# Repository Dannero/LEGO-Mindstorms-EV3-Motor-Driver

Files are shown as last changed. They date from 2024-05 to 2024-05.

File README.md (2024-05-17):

# LEGO Mindstorms EV3 Motor Driver

The following files are a part of my bachelor's thesis, in which I created custom motor driver PCBs with integrated microcontrollers, designed enclosures for these drivers, and created EV3-G blocks that allow the EV3 brick to communicate with the driver and carry out UART communication. 

---

### Driver_Arduino
This directory contains code for the [ev3dev](https://www.ev3dev.org/) OS and an Arduino Uno with an [Adafruit Motor Driver shield](https://learn.adafruit.com/adafruit-motor-shield/overview) and allows the EV3 with the ev3dev OS installed to control motors via I2C.

---

### Driver_V0.1
This directory contains the code for the first version of the custom driver in the `Driver_Code` directory, as well as PCB and 3D case files for manufacturing and printing. This PCB design is faulty and has some missing components, so I strongly advise to use the V0.2 driver.

---

### Driver_V0.2
Directory with source code and design files for the second iteration of the custom Driver, now more compact and able to run motors with higher performance, while being significantly more efficient in an idle state. 

---

### EV3-G_Blocks
Blocks for the *LEGO EV3 Lab Software* and their source code are situated in this directory. The `Thesis_Block.ev3b` allows the EV3 to communicate via the LEGO UART Sensor Protocol, built on the UART protocol, as well as control the motors connected to the motor driver via both I2C and the aforementioned UART-based protocols.

The `Dexter_Mod.ev3b` block is a modified version of the *Dexter Industries I2C Block*, available [here](https://github.com/DexterInd/EV3_Dexter_Industries_Sensors/blob/master/Dexter.ev3b). My modifications to this block fix the long-standing issue of the I2C communication functionality, where the maximum value of a sent byte is `0x7F`.

---

### Driver_Manual.pdf
This document contains all the necessary info to create the second version of the custom driver, get it up and running and use EV3-G block to control it.

---

### Future Work
The next iteration of the motor driver will take on a different approach, with the connection to the EV3 going wireless. Stay tuned!

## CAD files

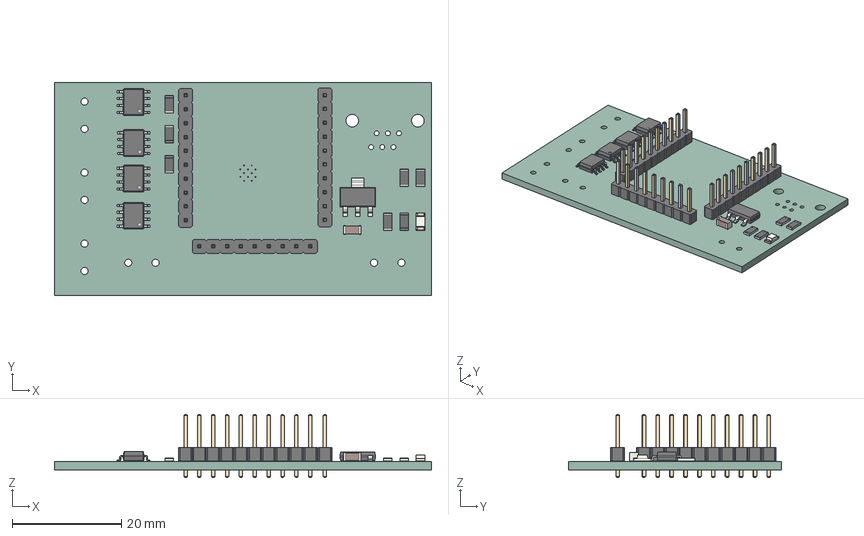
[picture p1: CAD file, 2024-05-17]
Driver_V0.2/V0.2_Case_Design/PCB/driver_v2.step
69.0 x 39.0 x 11.5 mm
SOIC_8_39x49mm_P127mm x 4
C_1206_3216Metric
R_1206_3216Metric x 7
PinHeader_1x09_P254mm_Vertical
PinHeader_1x10_P254mm_Vertical x 2
LED_1206_3216Metric
SOT_223
driver_v2_PCB

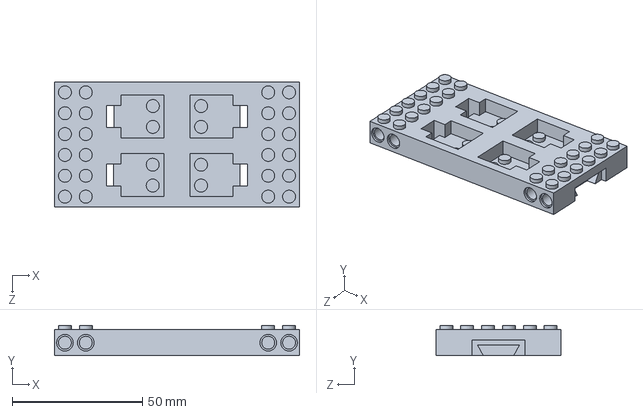
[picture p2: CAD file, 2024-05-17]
Driver_V0.2/V0.2_Case_Design/top.SLDPRT
94.0 x 11.7 x 48.0 mm

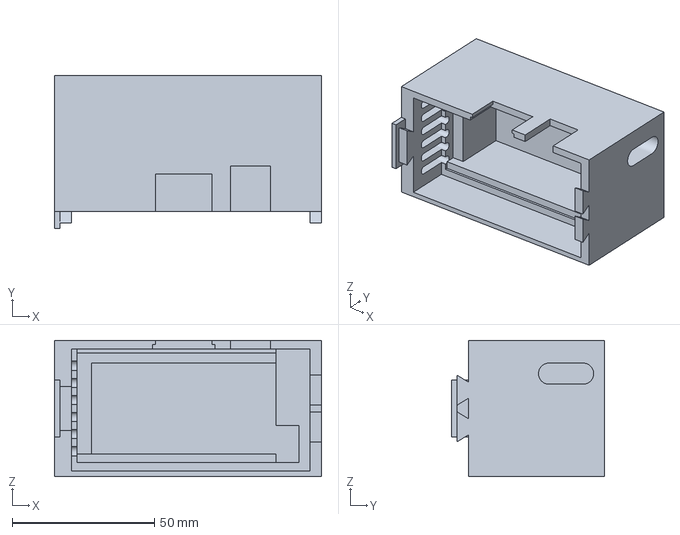
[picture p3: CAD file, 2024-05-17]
Driver_V0.2/V0.2_Print_Files/Bottom.3MF
94.0 x 54.0 x 48.0 mm

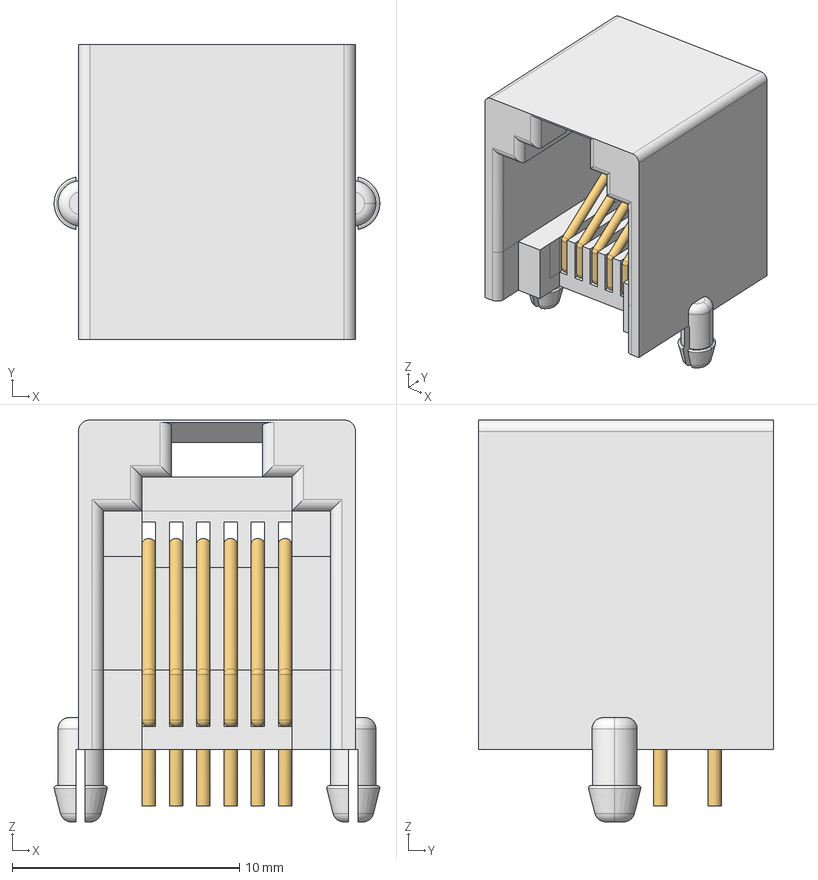
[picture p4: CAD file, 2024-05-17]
Driver_V0.2/V0.2_Case_Design/PCB/RJ12.step
14.3 x 13.0 x 17.7 mm

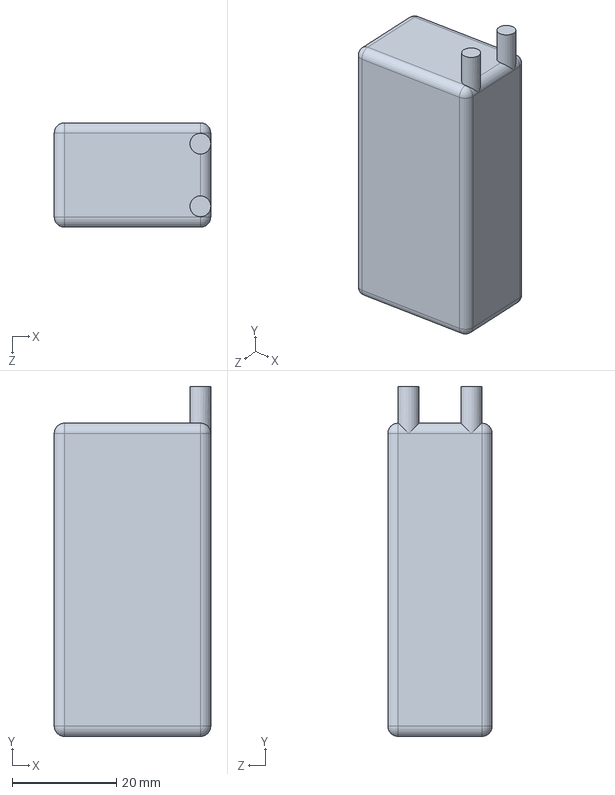
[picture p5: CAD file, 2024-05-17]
Driver_V0.2/V0.2_Case_Design/Battery.SLDPRT
30.0 x 67.0 x 20.0 mm

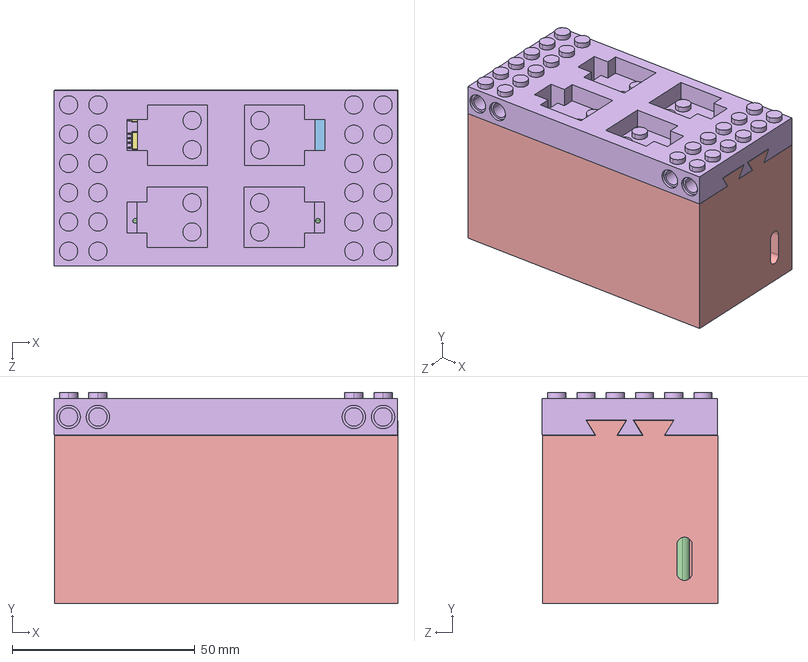
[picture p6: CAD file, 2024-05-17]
Driver_V0.2/V0.2_Case_Design/V0.2_Case.STEP
94.1 x 57.7 x 48.0 mm
Battery
bottom
top
SOIC_8_39x49mm_P127mm.step x 4
C_1206_3216Metric-0.step
R_1206_3216Metric-1.step x 7
PinHeader_1x09_P254mm_Vertical.step
PinHeader_1x10_P254mm_Vertical.step x 2
LED_1206_3216Metric-2.step
SOT_223.step
driver_v2_PCB.step

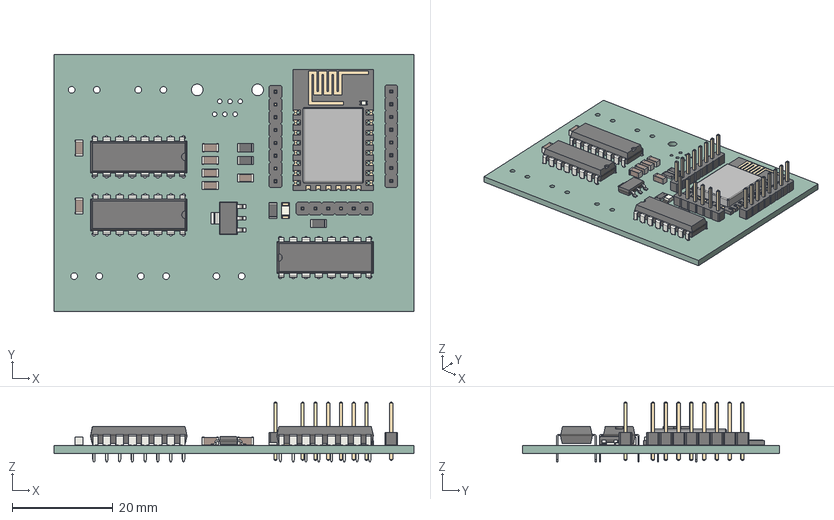
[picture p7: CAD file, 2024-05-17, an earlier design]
Driver_V0.1/V0.1_CAD_Files/driver.step
71.5 x 51.0 x 11.8 mm
DIP-16_W7.62mm x 3
C_1206_3216Metric x 7
R_1206_3216Metric x 4
PinHeader_1x06_P254mm_Vertical
LED_1206_3216Metric
SOT_223
PinHeader_1x08_P254mm_Vertical x 2
ESP_12E001_cp
driver_PCB

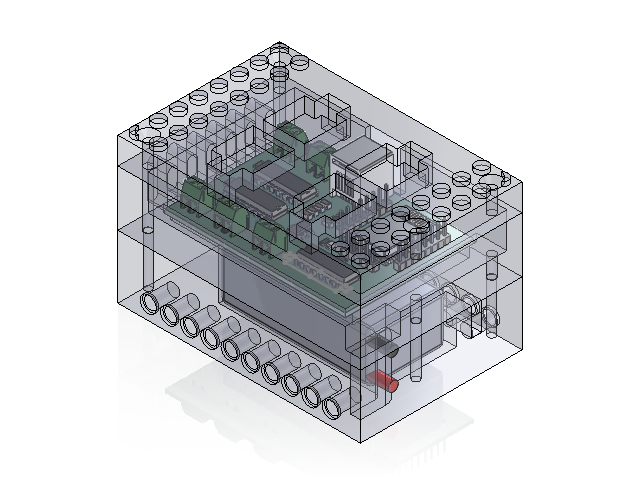
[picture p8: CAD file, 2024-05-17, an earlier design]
Driver_V0.1/V0.1_Case_Design/V0.1_Case.SLDASM
Bottom
Battery
DIP-16_W7.62mm x 3
C_1206_3216Metric x 7
R_1206_3216Metric x 4
PinHeader_1x06_P254mm_Vertical
LED_1206_3216Metric
SOT_223
PinHeader_1x08_P254mm_Vertical x 2
ESP_12E001_cp
driver_PCB
2445P Screw Terminal Block- 2 Pin, 3.5mm Pitch, Side Entry x 5
Mid
Top

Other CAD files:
Driver_V0.2/V0.2_Case_Design/bottom.SLDPRT
Driver_V0.2/V0.2_Print_Files/Top.3MF
Driver_V0.1/V0.1_Case_Design/PCB/DIP-16_W7.62mm.SLDASM
Driver_V0.1/V0.1_Case_Design/PCB/C_1206_3216Metric.SLDASM
Driver_V0.1/V0.1_Case_Design/PCB/R_1206_3216Metric.SLDASM
Driver_V0.1/V0.1_Case_Design/PCB/LED_1206_3216Metric.SLDASM
Driver_V0.1/V0.1_Case_Design/PCB/ESP-12E.SLDASM
Driver_V0.1/V0.1_Case_Design/PCB/PinHeader_1x08_P2.54mm_Vertical.SLDASM
Driver_V0.1/V0.1_Case_Design/PCB/SOT-223.SLDASM
Driver_V0.1/V0.1_Case_Design/PCB/PinHeader_1x06_P2.54mm_Vertical.SLDASM
Driver_V0.1/V0.1_Case_Design/Bottom.SLDPRT
Driver_V0.1/V0.1_Case_Design/Mid.SLDPRT
Driver_V0.1/V0.1_Case_Design/PCB/2445P Screw Terminal Block- 2 Pin, 3.5mm Pitch, Side Entry.SLDPRT
Driver_V0.1/V0.1_Case_Design/PCB/C_1206_3216Metric.SLDPRT
Driver_V0.1/V0.1_Case_Design/PCB/DIP-16_W7.62mm.SLDPRT
Driver_V0.1/V0.1_Case_Design/PCB/ESP_12E001_cp.SLDPRT
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

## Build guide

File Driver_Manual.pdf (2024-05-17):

# Manual for Creating and Using the V0.2 Motor Driver

This manual closely describes the process of creating the version 0.2 of the motor driver. Additionally, the manual includes the necessary steps to install custom blocks in the EV3 programming software and use them to communicate with the driver and control motors connected to it.

### Printed Circuit Board

The repository includes the necessary files to get the printed circuit board manufactured. The following components are necessary for the board to be functional:

- ESP32-WROOM-32E microcontroller module
- AMS1117-3.3 linear voltage regulator
- Microchip TC4427COA MOSFET motor driver (x4)
- 22μF SMD capacitor
- 330Ω SMD resistor
- 10kΩ SMD resistor (x3)
- 120kΩ SMD resistor
- 3.3V SMD LED diode
- RJ12 socket with a horizontal layout
- 2-pin screw terminal with a 5mm pitch, capable of handling at least 6A (x5)
- Pin header with a 2.54mm pitch (x6 min., OPTIONAL)
- 82KΩ SMD resistor (x2, OPTIONAL)

The resistors, the diode, and the capacitor are all of an SMD (surface mount device) 1206 footprint. For the component placement, use the schematic in Driver_V0.2/ V0.2_CAD_Files/schematic_V0.2.pdf and the silkscreen of the PCB for guidance. Begin the soldering process with the SMD components first. Start off with the resistors, the capacitor and the LED, followed by the voltage regulator, motor drivers, and finally the ESP32 MCU. The board has thermal relief polygons connected to the ground, so heating

1

up the GND pins of the components might take longer compared to other pins. After all of the SMD components have been soldered onto the board, solder the THT (throughhole technology) components, beginning with the shortest components, the screw terminals. Soldering pins headers is optional, however, it is strongly recommended as it makes the programming of the microcontroller significantly easier. The minimum number of pin headers that I recommend solder is six, for the GND, 3V3, EN, IO0, TX0, and RX0 pins, however, soldering pin headers for all GPIO pins can help with a diagnostic or debugging process, should such circumstances occur. Lastly, solder the RJ12 socket in place. The R1 and R2 82K pull-up resistors need not be soldered in place, unless you plan to communicate with the EV3 via the I2C protocol. These resistors are necessary for the communication to work correctly according to the EV3 Hardware Developer Kit¹

### 3D Printed Driver Enclosure and Driver Assembly

The Driver_V0.2/V0.2_Print_Files directory contains the Top.3MF and Bottom.3MF files for printing the enclosure of the driver. Use a freely available software, such as UltiMaker Cura to prepare the files for printing. As this version of the casing has notably narrower walls on it lower portion, I recommend choosing the cubic infill pattern with a 20% infill ratio to retain the structural integrity of the enclosure. If the sliding and locking mechanism does not work correctly, I recommend smoothing the inner surface of the rails with sandpaper. The battery I used for this driver is KAVAN Li-Po 850mAh/11,1V 40/80C 9,4Wh. After placing the battery in the lower part of the driver, place the PCB onto the platform above the battery (Figure 1). For switching the driver on and off, use a KDC1-101 rocker switch and put it into the opening above the PCB. Solder the positive (red) cable onto one pin and a wire on the second pin. Use a heat-shrinking tube or tape to isolate the connections. Screw the other end of the wire into the positive terminal of the PCB, denoted by the “+” sign of the battery terminal. Afterwards, screw the negative (black) cable of the battery to the “-” terminal.
For the Power Functions connectors on top of the enclosure, cut two PF cables into half. Strip the two middle wires and increase the rigidity of the stripped wire by using crimping pliers with wire terminals, or putting a small amount of solder onto the wire. Push the wires through the openings on the upper part of the enclosure, then screw the cables into the M1, M2, M3, and M4 terminals. Finally, slide the driver case closed. After turning on the driver, it automatically enters pairing mode with the EV3, shown by the slow flashing of the status LED. If the device is connected, the LED stays on in a dimmer mode and if the battery of the driver is low, the LED flashes fast for ten seconds before the MCU enters a deep sleep mode. Afterwards, it is necessary to charge the battery. Turning the driver on and off resets the drivers, which then resumes regular operation.
While the EV3 uses RJ12 ports, the latch on the connector is offset to the side. To create a compatible cable, cut the end of an EV3 cable, strip the wires, then place them in an RJ12 connector with a centered latch, and use a crimping tool to secure the cables in the connector. Alternatively, you can remove the latch of the EV3 connector and use this to connect to the driver, however, note that the connector will not be secured. An image of the driver connected to the EV3 and the motors can be seen in Figure 3.

1
https://education.lego.com/en-us/product-resources/mindstorms-ev3/downloads/developerkits/ (https://education.lego.com/en-us/product-resources/mindstorms-ev3/downloads/developer-kits/)

2

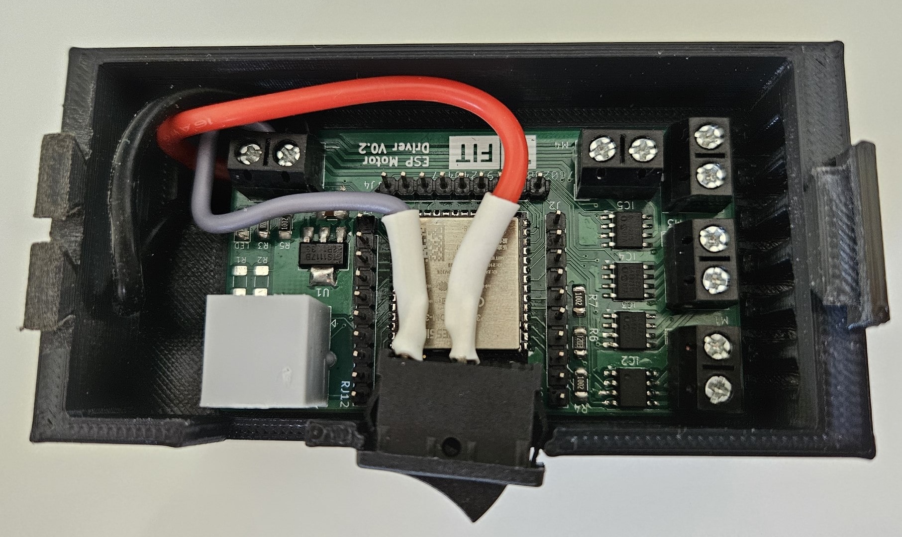
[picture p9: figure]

Figure 1: Assembly of the motor driver

### Programming the Microcontroller

To program the microcontroller, use an Espressif ESP-Prog programmer or an equivalent alternative device. Connect the 6 pins (GND, VP ROG, EN, IO0, TX0, RX0) to the corresponding pins of the MCU (Figure 2). Do not forget to remove the jumper for the VP ROG pin if you program the MCU while connected to an external power source. Use Arduino IDE software or the Visual Studio Code editor with PlatformIO IDE extension to flash the files located in the Driver_V0.2/Driver_Code directory of the repository after choosing the correct device in the board menu. When the ESP-Prog is connected, it uses two COM ports, use the latter one to program the board.

### Using the EV3 Software

Download the EV3 Lab Software²and install the app on your device. To import new blocks, firstly create a new project program, then navigate to the Tools tab. There, select Block Import, find the motor block in the wizard (EV3-G_Blocks/Thesis_Block.ev3b in the repository), then press Import. The software then prompts you to restart it. Afterwards, the motor control block will be available for use in the Sensor section of the blocks. Create a program for the brick, which should begin with the Start block and conclude with the Stop Program block. Add the motor block to the program and choose one of the UART modes of the block to control the motors, filling out the desired parameters. Connect the EV3 brick to your computer via cable, Bluetooth, or Wi-Fi, then download the program to the brick and run it. A picture of the EV3 software interface can be seen in Figure 4. Object number one shows a program example, where all motors are set to run with a duty cycle of 10 out of 15 for ten seconds, then stop for three seconds in an indefinite loop. Number two shows the command block tray with Sensor blocks selected, while number three points to the Motor Control block. Buttons for downloading the program to the brick

2
https://education.lego.com/es-mx/downloads/retiredproducts/mindstorms-ev3-lab/software/

3

and running it are located by marker number four. Marker number five shows the Tools tab, where the Block Import wizard is located.

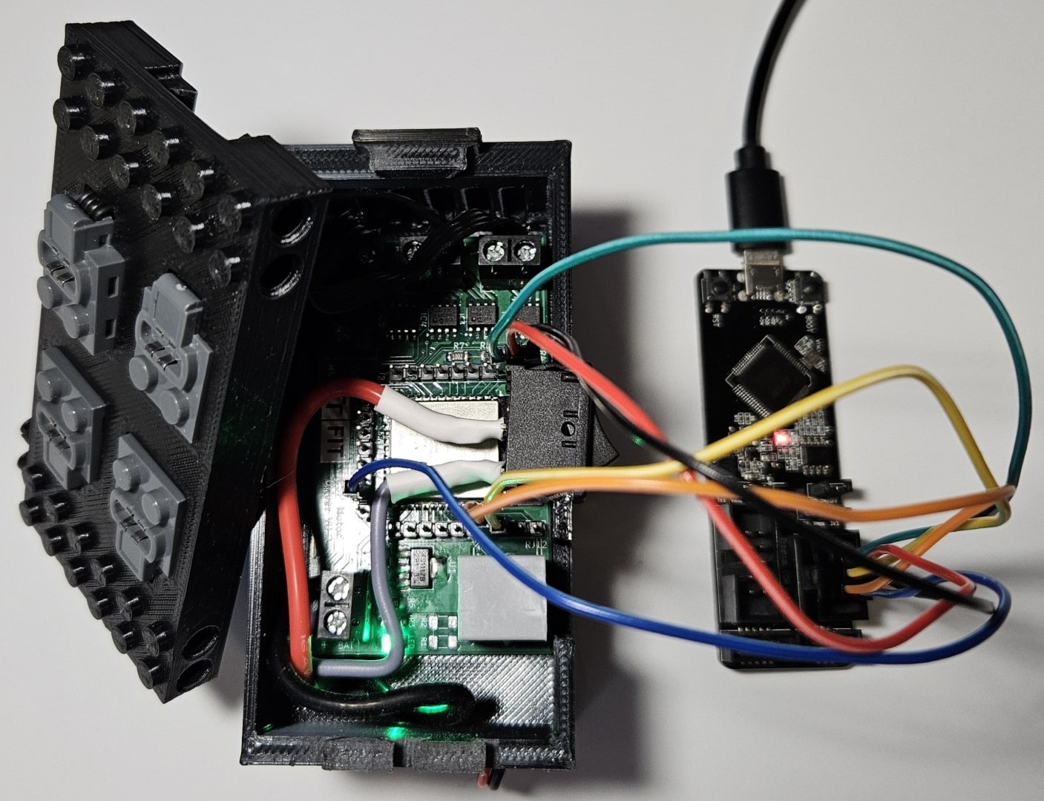
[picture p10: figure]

Figure 2: Programming the motor driver V0.2 with an Espressif ESP-Prog

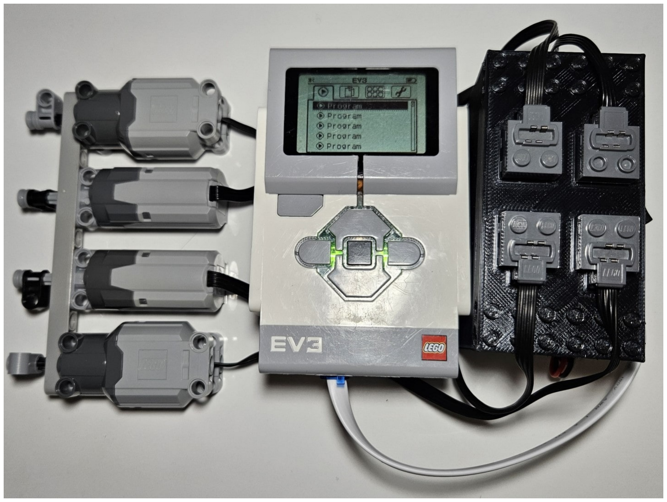
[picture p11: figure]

Figure 3: Driver V0.2 connected to the EV3 and four Power Functions motors

4

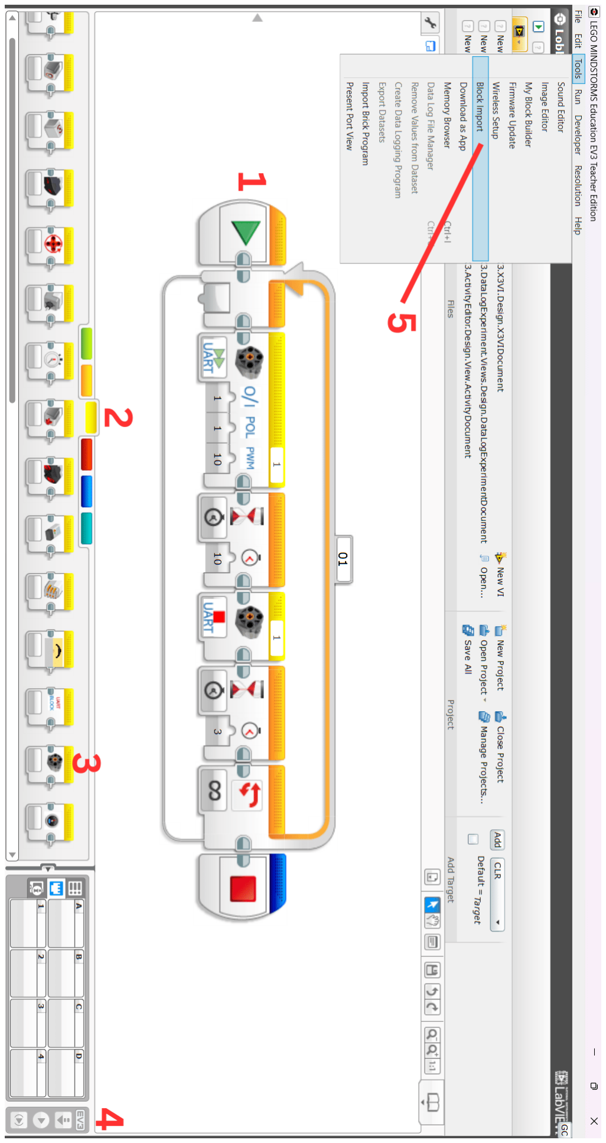
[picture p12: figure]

Figure 4: EV3 Lab Software

5

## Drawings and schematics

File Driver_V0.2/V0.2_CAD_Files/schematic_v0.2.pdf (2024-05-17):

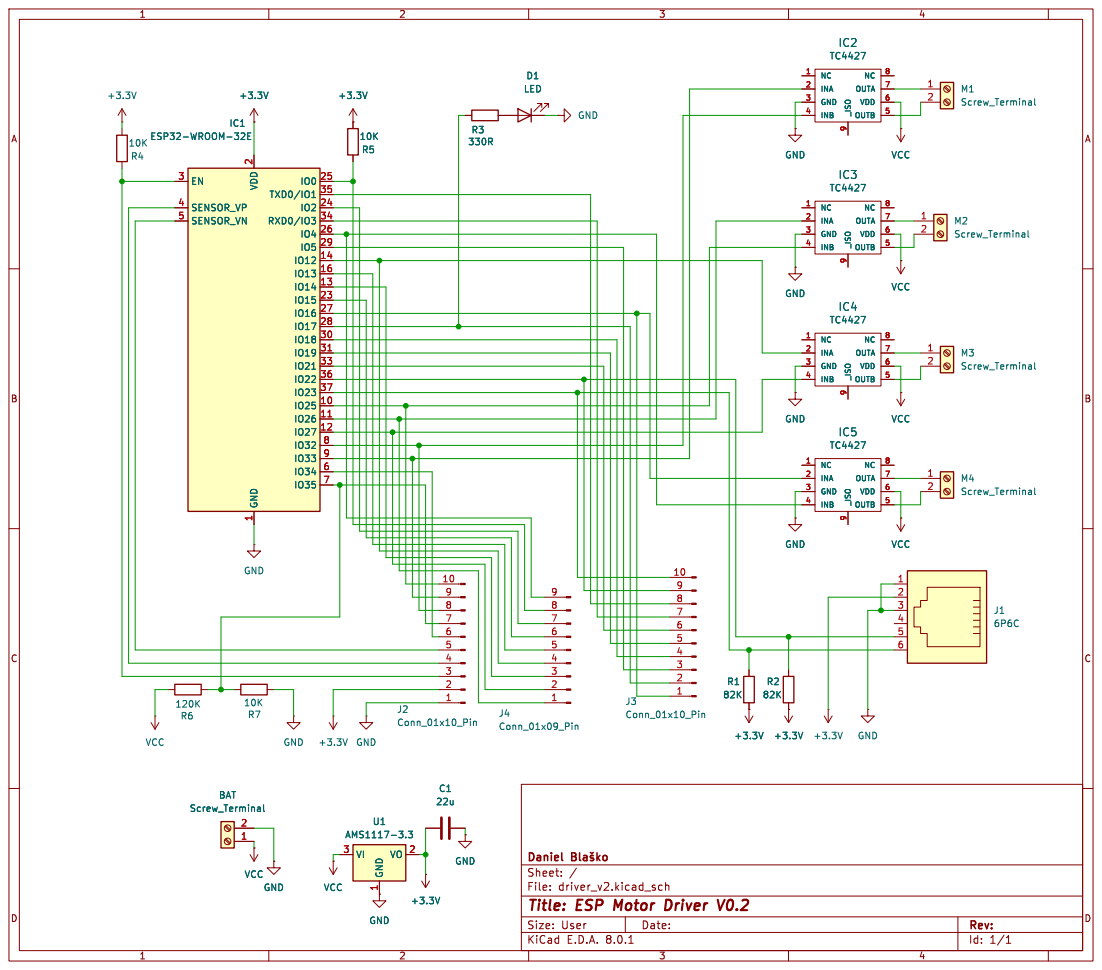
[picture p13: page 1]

Id: 1/1 Title: ESP Motor Driver V0.2

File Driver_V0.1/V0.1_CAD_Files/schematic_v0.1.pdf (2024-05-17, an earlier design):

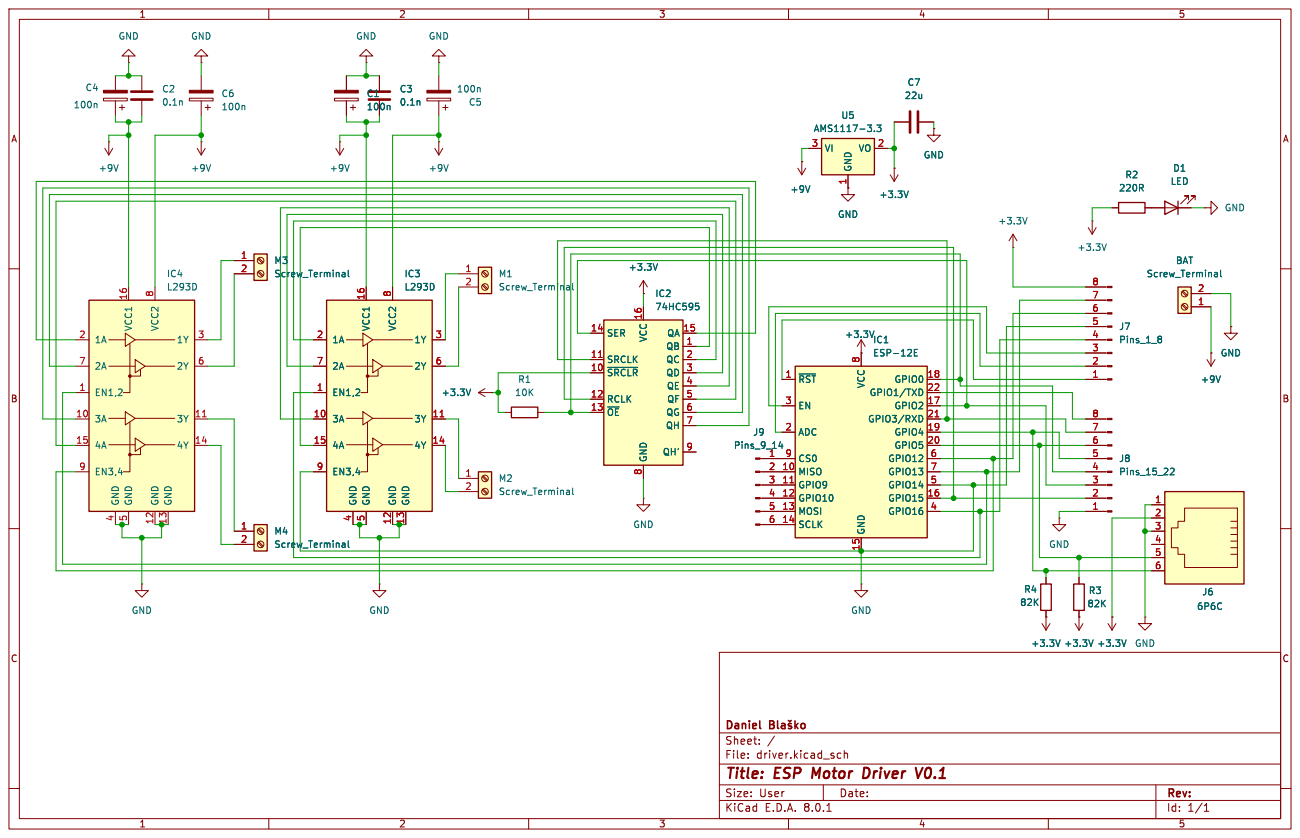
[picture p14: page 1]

Id: 1/1 Title: ESP Motor Driver V0.1

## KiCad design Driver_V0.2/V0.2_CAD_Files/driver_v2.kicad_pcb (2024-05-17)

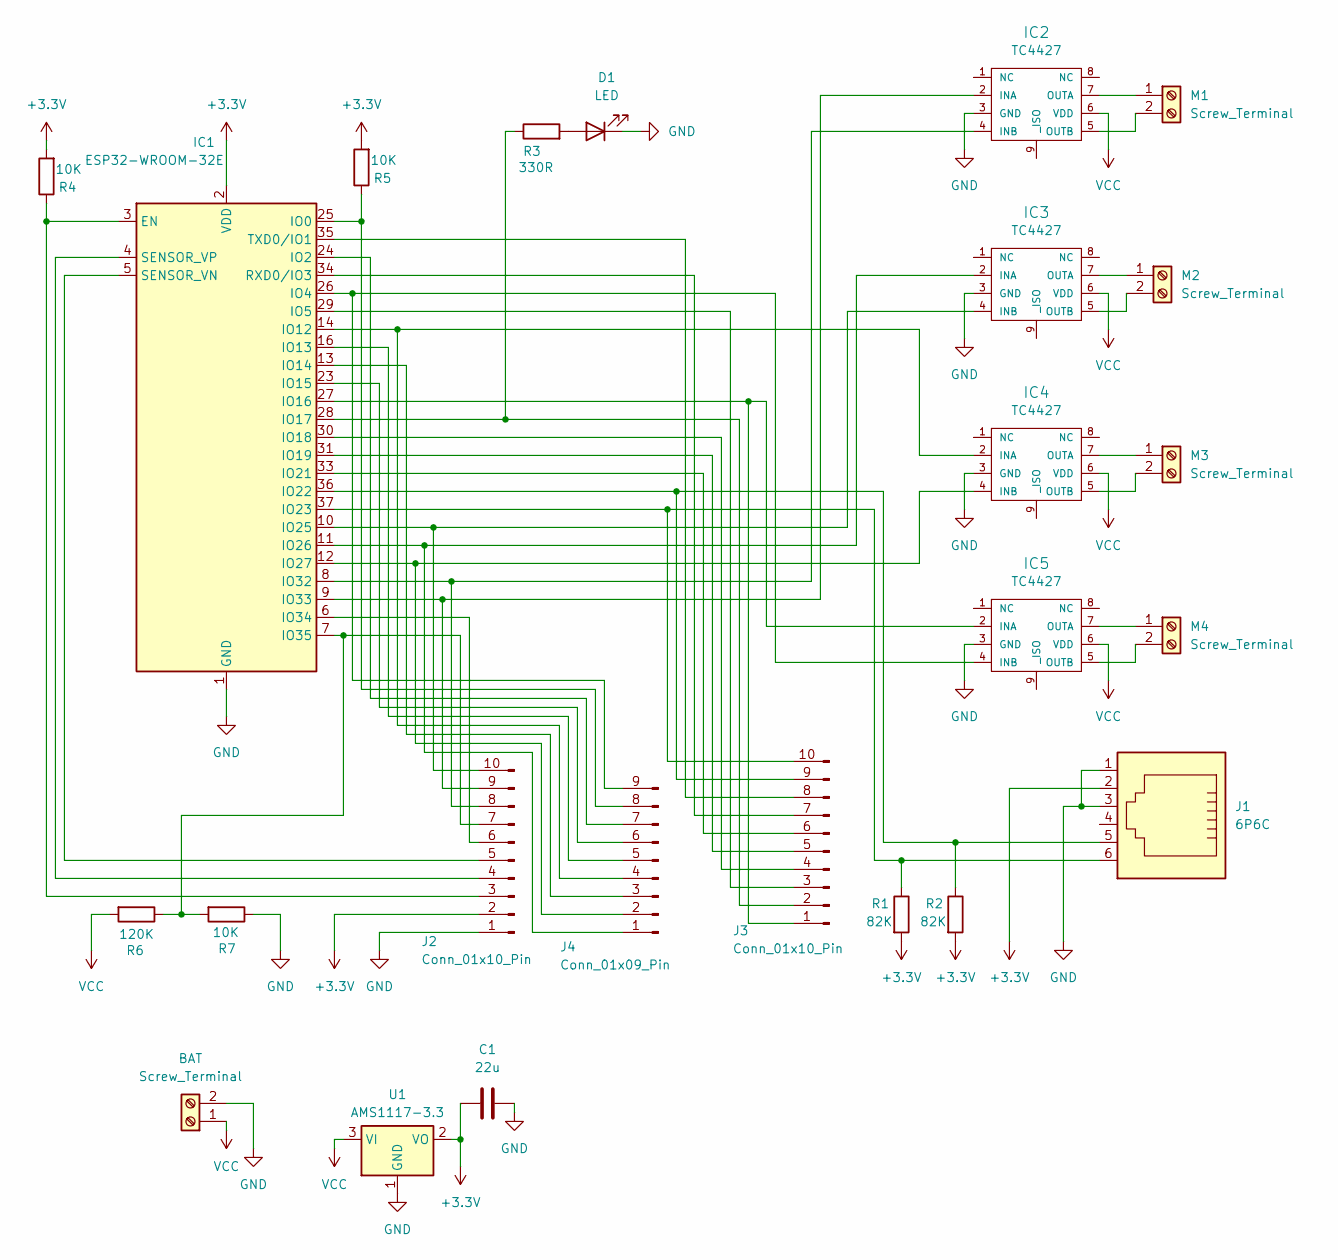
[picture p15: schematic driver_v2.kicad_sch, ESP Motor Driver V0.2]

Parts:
BAT: Screw_Terminal; TerminalBlock_MetzConnect_Type055_RT01502HDWU_1x02_P5.00mm_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
C1: 22u; C_1206_3216Metric_Pad1.33x1.80mm_HandSolder
D1: LED; LED_1206_3216Metric_Pad1.42x1.75mm_HandSolder
IC1: ESP32-WROOM-32E; ESP32-WROOM-32E-SMALL-KEEPOUT
IC2, IC3, IC4, IC5: TC4427; SOIC-8_3.9x4.9mm_P1.27mm
J1: 6P6C; RJ25_Wayconn_MJEA-660X1_Horizontal
J2, J3: Conn_01x10_Pin; PinHeader_1x10_P2.54mm_Vertical
J4: Conn_01x09_Pin; PinHeader_1x09_P2.54mm_Vertical
M1, M2, M3, M4: Screw_Terminal; TerminalBlock_MetzConnect_Type055_RT01502HDWU_1x02_P5.00mm_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
R1, R2: 82K; R_1206_3216Metric_Pad1.30x1.75mm_HandSolder
R3: 330R; R_1206_3216Metric_Pad1.30x1.75mm_HandSolder
R4, R5, R7: 10K; R_1206_3216Metric_Pad1.30x1.75mm_HandSolder
R6: 120K; R_1206_3216Metric_Pad1.30x1.75mm_HandSolder
U1: AMS1117-3.3; SOT-223-3_TabPin2

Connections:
+3.3V: C1.1, IC1.2 (VDD), J1.2, J2.2, R1.2, R2.2, R4.2, R5.2, U1.2 (VO)
GND: BAT.2, C1.2, D1.1 (K), IC1.1 (GND), IC1.15 (GND), IC1.38 (GND), IC1.39 (GND), IC2.3 (GND), IC3.3 (GND), IC4.3 (GND), IC5.3 (GND), J1.1, J1.3, J2.1, R7.1, U1.1 (GND); also elsewhere on the board
unnamed: D1.2 (A), R3.2
unnamed: IC1.3 (EN), J2.3, R4.1
unnamed: IC1.25 (IO0), J4.8, R5.1
unnamed: IC1.24 (IO2), J4.7
unnamed: IC1.26 (IO4), IC5.4 (INB), J4.9
unnamed: IC1.29 (IO5), J3.3
unnamed: IC1.14 (IO12), IC4.2 (INA), J4.4
unnamed: IC1.16 (IO13), J4.5
unnamed: IC1.13 (IO14), J4.3
unnamed: IC1.23 (IO15), J4.6
unnamed: IC1.27 (IO16), IC5.2 (INA), J3.1
unnamed: IC1.28 (IO17), J3.2, R3.1
unnamed: IC1.30 (IO18), J3.4
unnamed: IC1.31 (IO19), J3.5
unnamed: IC1.33 (IO21), J3.6
unnamed: IC1.36 (IO22), J1.5, J3.9, R2.1
unnamed: IC1.37 (IO23), J1.6, J3.10, R1.1
unnamed: IC1.10 (IO25), IC3.4 (INB), J2.10
unnamed: IC1.11 (IO26), IC3.2 (INA), J4.1
unnamed: IC1.12 (IO27), IC4.4 (INB), J4.2
unnamed: IC1.8 (IO32), IC2.4 (INB), J2.8
unnamed: IC1.9 (IO33), IC2.2 (INA), J2.9
unnamed: IC1.6 (IO34), J2.6
unnamed: IC1.7 (IO35), J2.7, R6.1, R7.2
unnamed: IC1.34 (RXD0/IO3), J3.7
unnamed: IC1.5 (SENSOR_VN), J2.5
unnamed: IC1.4 (SENSOR_VP), J2.4
unnamed: IC1.35 (TXD0/IO1), J3.8
unnamed: IC2.7 (OUTA), M1.1
unnamed: IC2.5 (OUTB), M1.2
unnamed: IC3.7 (OUTA), M2.1
unnamed: IC3.5 (OUTB), M2.2
unnamed: IC4.7 (OUTA), M3.1
unnamed: IC4.5 (OUTB), M3.2
unnamed: IC5.7 (OUTA), M4.1
unnamed: IC5.5 (OUTB), M4.2
VCC: BAT.1, IC2.6 (VDD), IC3.6 (VDD), IC4.6 (VDD), IC5.6 (VDD), R6.2, U1.3 (VI); also elsewhere on the board

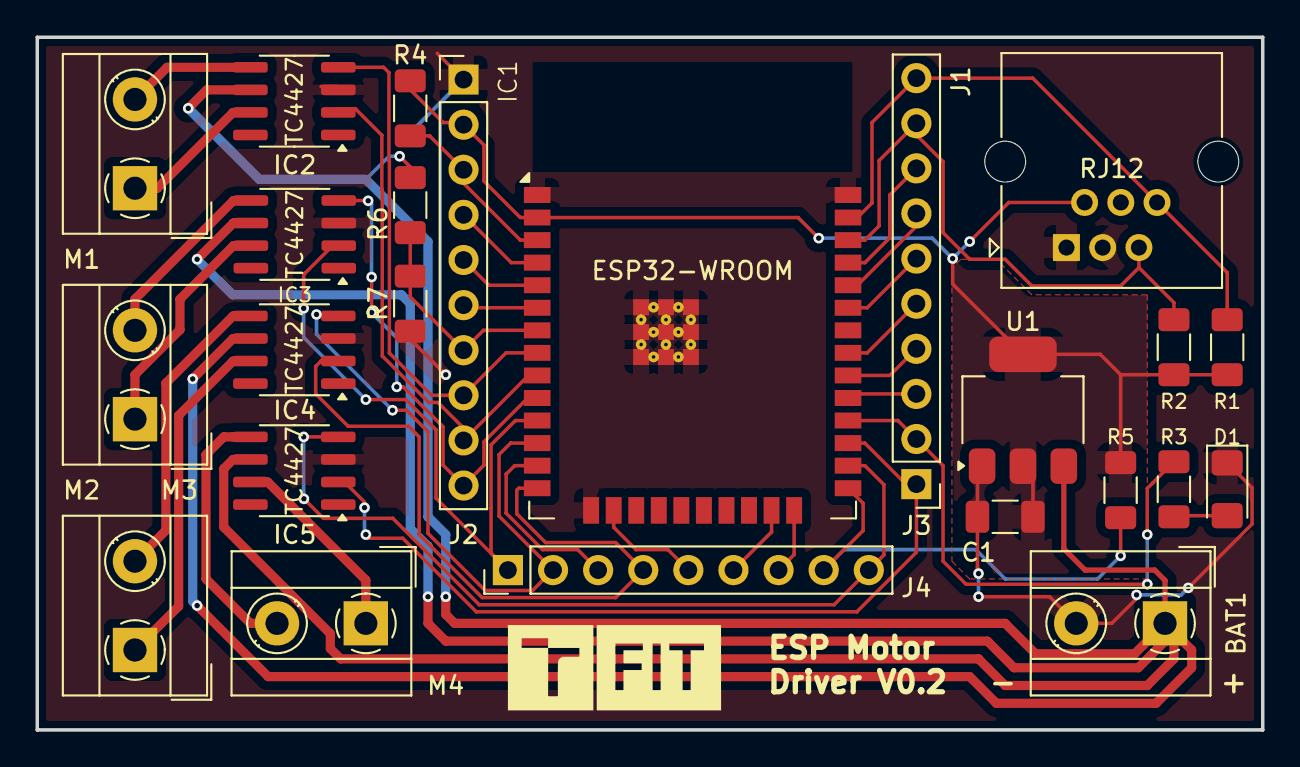
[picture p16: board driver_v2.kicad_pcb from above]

Board: 2 copper layers, 69.0 x 39.0 mm, 24 parts (0 on the bottom side), 39 nets.

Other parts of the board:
BAT1: Screw_Terminal_01x02; TerminalBlock_MetzConnect_Type055_RT01502HDWU_1x02_P5.00mm_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

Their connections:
GND: BAT1.2; also elsewhere on the board
VCC: BAT1.1; also elsewhere on the board

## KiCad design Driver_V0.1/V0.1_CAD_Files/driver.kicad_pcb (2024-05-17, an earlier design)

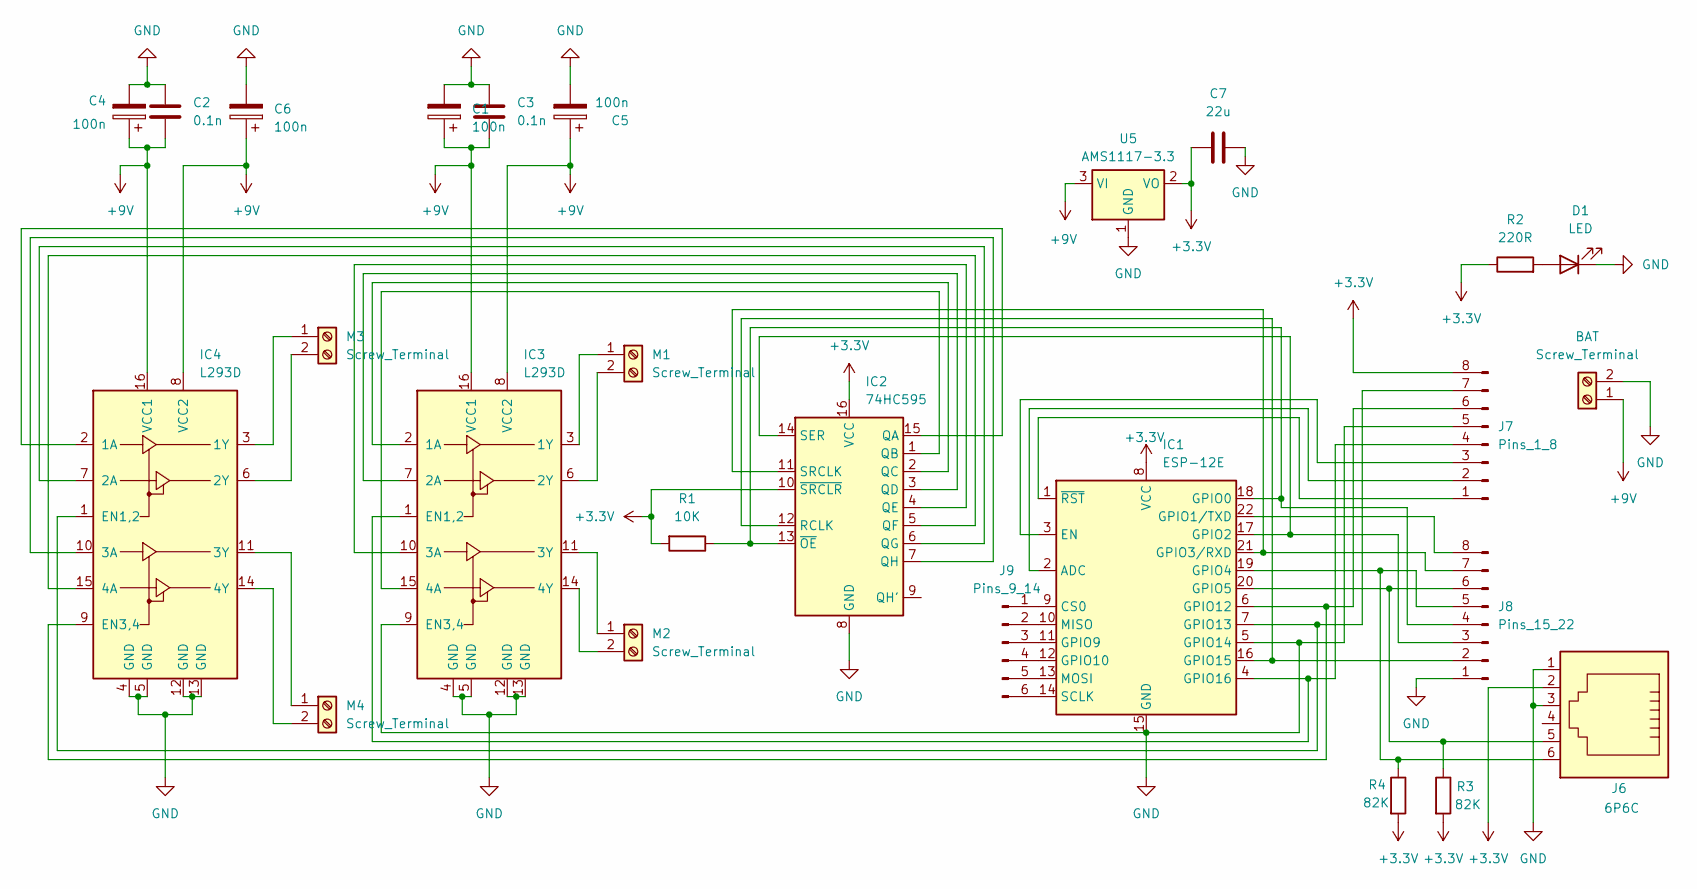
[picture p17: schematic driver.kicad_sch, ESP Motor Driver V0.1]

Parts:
BAT: Screw_Terminal; TerminalBlock_Altech_AK300-2_P5.00mm
C1, C4, C5, C6: 100n; C_1206_3216Metric_Pad1.33x1.80mm_HandSolder
C2, C3: 0.1n; C_1206_3216Metric_Pad1.33x1.80mm_HandSolder
C7: 22u; C_1206_3216Metric_Pad1.33x1.80mm_HandSolder
D1: LED; LED_1206_3216Metric_Pad1.42x1.75mm_HandSolder
IC1: ESP-12E
IC2: 74HC595; DIP-16_W7.62mm
IC3, IC4: L293D; DIP-16_W7.62mm
J6: 6P6C; RJ25_Wayconn_MJEA-660X1_Horizontal
J7: Pins_1_8; PinHeader_1x08_P2.54mm_Vertical
J8: Pins_15_22; PinHeader_1x08_P2.54mm_Vertical
J9: Pins_9_14; PinHeader_1x06_P2.54mm_Vertical
M1, M2, M3, M4: Screw_Terminal; TerminalBlock_Altech_AK300-2_P5.00mm
R1: 10K; R_1206_3216Metric_Pad1.30x1.75mm_HandSolder
R2: 220R; R_1206_3216Metric_Pad1.30x1.75mm_HandSolder
R3, R4: 82K; R_1206_3216Metric_Pad1.30x1.75mm_HandSolder
U5: AMS1117-3.3; SOT-223-3_TabPin2

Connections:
+3.3V: C7.1, IC1.8 (VCC), IC2.10 (~SRCLR), IC2.16 (VCC), J6.2, J7.8, R1.2, R2.1, R3.2, R4.2, U5.2 (VO); also elsewhere on the board
+9V: BAT.1, C1.1, C2.2, C3.2, C4.1, C5.1, C6.1, IC3.8 (VCC2), IC3.16 (VCC1), IC4.8 (VCC2), IC4.16 (VCC1), U5.3 (VI)
unnamed: D1.2 (A), R2.2
unnamed: IC1.2 (ADC), J7.2
unnamed: IC1.9 (CS0), J9.1
unnamed: IC1.3 (EN), J7.3
unnamed: IC1.18 (GPIO0), IC2.13 (~OE), J8.4, R1.1
unnamed: IC1.22 (GPIO1/TXD), J8.8
unnamed: IC1.17 (GPIO2), IC2.14 (SER), J8.3
unnamed: IC1.21 (GPIO3/RXD), IC2.11 (SRCLK), J8.7
unnamed 10: IC1.19 (GPIO4), J6.6, J8.5, R4.1; also elsewhere on the board
unnamed 11: IC1.20 (GPIO5), J6.5, J8.6, R3.1; also elsewhere on the board
unnamed: IC1.11 (GPIO9), J9.3
unnamed: IC1.12 (GPIO10), J9.4
unnamed: IC1.6 (GPIO12), IC4.9 (EN3,4), J7.6
unnamed: IC1.7 (GPIO13), IC4.1 (EN1,2), J7.7
unnamed: IC1.16 (GPIO15), IC2.12 (RCLK), J8.2
unnamed: IC1.4 (GPIO16), IC3.1 (EN1,2), J7.4
unnamed: IC1.10 (MISO), J9.2
unnamed: IC1.13 (MOSI), J9.5
unnamed: IC1.14 (SCLK), J9.6
unnamed: IC1.1 (~RST), J7.1
unnamed: IC2.15 (QA), IC4.2 (1A)
unnamed: IC2.1 (QB), IC3.15 (4A)
unnamed: IC2.2 (QC), IC3.2 (1A)
unnamed: IC2.3 (QD), IC3.7 (2A)
unnamed: IC2.4 (QE), IC3.10 (3A)
unnamed: IC2.5 (QF), IC4.15 (4A)
unnamed: IC2.6 (QG), IC4.7 (2A)
unnamed: IC2.7 (QH), IC4.10 (3A)
unnamed: IC3.3 (1Y), M1.1
unnamed: IC3.6 (2Y), M1.2
unnamed: IC3.11 (3Y), M2.1
unnamed: IC3.14 (4Y), M2.2
unnamed: IC4.3 (1Y), M3.1
unnamed: IC4.6 (2Y), M3.2
unnamed: IC4.11 (3Y), M4.1
unnamed: IC4.14 (4Y), M4.2

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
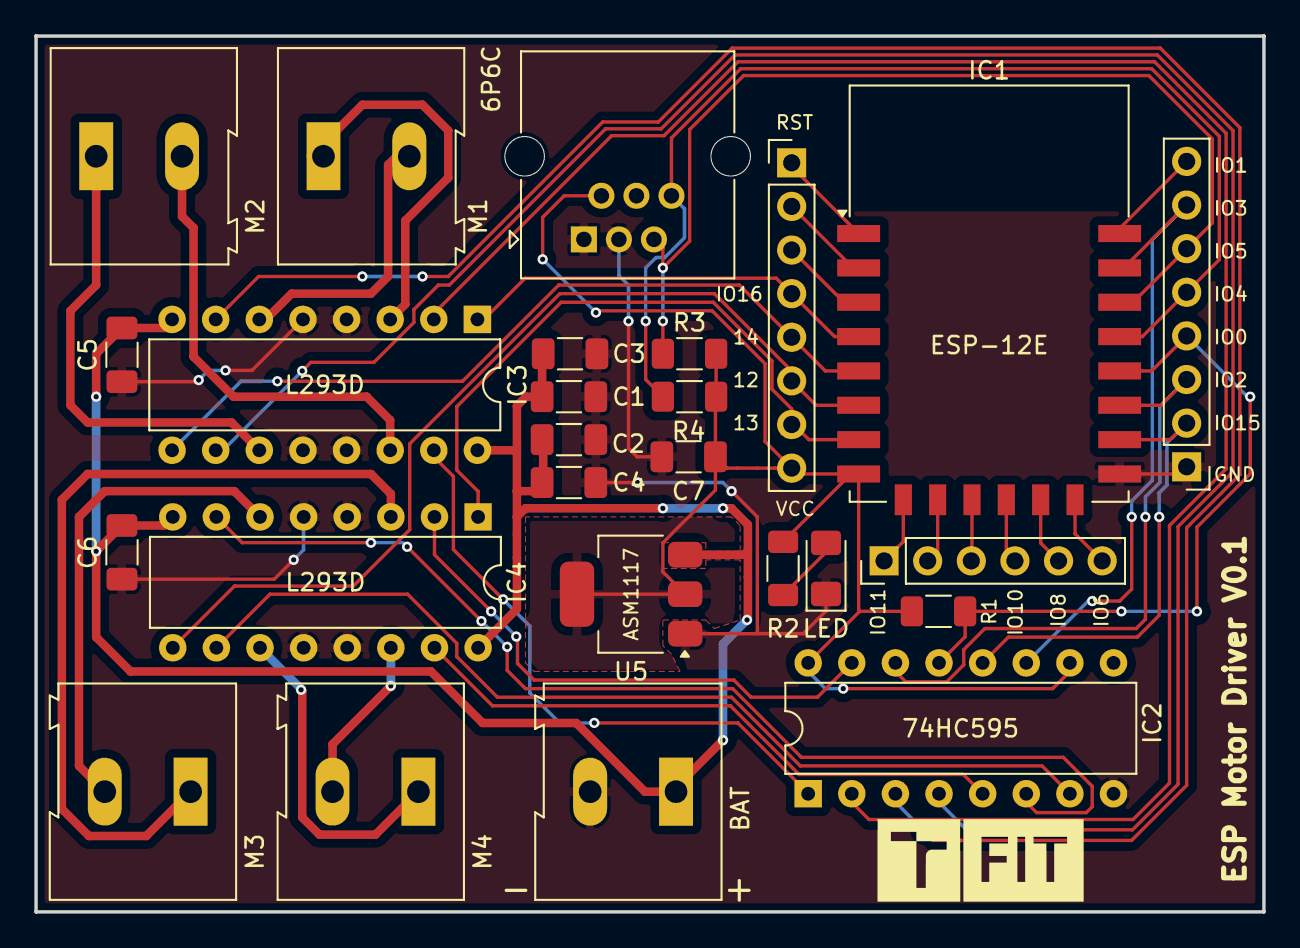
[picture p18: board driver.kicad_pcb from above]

Board: 2 copper layers, 71.5 x 51.0 mm, 26 parts (0 on the bottom side), 40 nets.

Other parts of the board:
6P6C: 6P6C; RJ25_Wayconn_MJEA-660X1_Horizontal

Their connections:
+3.3V: 6P6C.2; also elsewhere on the board
unnamed 10: 6P6C.6; also elsewhere on the board
unnamed 11: 6P6C.5; also elsewhere on the board

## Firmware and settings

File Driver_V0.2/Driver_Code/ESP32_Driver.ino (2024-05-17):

/*
* File:   ESP32_Driver.ino
*
* Desc:   ESP-WROOM32E Arduino framework program for communicating with a LEGO Mindstorms EV3 brick
*         using the LEGO UART Sensor Protocol and running motors PWM
*
* Author: Daniel Blaško
*/

#include "ESP32_Driver.h"

uint8_t state = 0;
bool break_cond_ongoing = false;
bool break_high_ongoing = false;
bool handshake_finished = false;
bool checksum_expected = false;

unsigned long current_millis = 0;
unsigned long previous_millis = 0;
unsigned long last_write_millis = 0;
unsigned long last_nack_millis = 0;
unsigned long break_cond_millis = 0;
unsigned long break_high_millis = 0;
unsigned long last_voltage_read_millis = 0;
unsigned long low_voltage_trigger_millis = 0;
unsigned long led_current_millis = 0;
unsigned long led_previous_millis = 0;

uint8_t val = 0;
uint8_t bytes_to_read;  //Set number of bytes to read from the WRITE EV3 Message (ref: https://sourceforge.net/p/lejos/wiki/UART%20Sensor%20Protocol/)
uint16_t voltage_readout = 0; //Value of the ADC pin readout
uint8_t led_duty_cycle = 0;

// Moving average variables
uint8_t avg_index = 0;
uint16_t avg_window[AVG_WINDOW_SIZE];

//Set up all four motors
Motor motor1(1);
Motor motor2(2);
Motor motor3(3);
Motor motor4(4);
//Array of motors (easier motor setting by just setting the motor at a parsed index)
Motor motors[4] = {motor1, motor2, motor3, motor4};
uint8_t motor_pwms[4] = {0,0,0,0};
uint8_t pwm_send_index = 0;

SoftwareSerial soft_serial(RX_PIN, TX_PIN);


void Handshake(SoftwareSerial &soft_serial) {
  //TYPE
  soft_serial.write(0x40);
  soft_serial.write(0x64); //type - 100
  soft_serial.write(0xDB); //XOR

  //MODES 
  soft_serial.write(0x49); //Mode 0
  soft_serial.write('\0'); 
  soft_serial.write('\0');
  soft_serial.write(0xB6); //XOR


  //Communication speed (Optional, if not specified, then stays at 2400 baud) 
  //57600 (Little endian)
  soft_serial.write(0x52);
  soft_serial.write('\0');
  soft_serial.write(0xE1);
  soft_serial.write('\0');
  soft_serial.write('\0');
  soft_serial.write(0x52 ^ '\0' ^ 0xE1 ^ '\0' ^ '\0' ^ 0xFF);

  //Mode 0 Name
  soft_serial.write(0x90);
  soft_serial.write('\0'); 
  soft_serial.write(0x75); //u
  soft_serial.write(0x61); //a
  soft_serial.write(0x72); //r
  soft_serial.write(0x74); //t
  soft_serial.write(0x90 ^ '\0' ^ 0x75 ^ 0x61 ^ 0x72 ^ 0x74 ^ 0xFF); //XOR

  // RAW value range (32bit floating point)
  soft_serial.write(0x98);
  soft_serial.write(0x01);
  soft_serial.write('\0');  //Min value: 0
  soft_serial.write('\0');
  soft_serial.write('\0');
  soft_serial.write('\0');
  soft_serial.write('\0'); //Max value: 255
  soft_serial.write('\0');
  soft_serial.write(0x7F);
  soft_serial.write(0x43);
  soft_serial.write(0x98 ^ 0x01 ^ '\0' ^ 0x7F ^ 0x43 ^ 0xFF); //XOR

  //FORMAT
  soft_serial.write(0x90);
  soft_serial.write(0x80);
  soft_serial.write(0x01); //1 item
  soft_serial.write('\0'); //Data type 0 - 8bit int
  soft_serial.write(0x03); //Number of digits to show
  soft_serial.write('\0'); //Number of decimals to show
  soft_serial.write(0x90 ^ 0x80 ^ 0x01 ^ '\0' ^ 0x03 ^ '\0' ^ 0xFF); //XOR

  //ACK
  soft_serial.write(0x04);
}


void setup() {
  //Pin OUTPUT mode for 500ms UART break condition
  pinMode(TX_PIN, OUTPUT); 
  soft_serial.begin(DEFAULT_BAUD_RATE);
  // Default state, trying to connect to EV3
  state = HANDSHAKE;
  // Set up LED PWM channel and pin
  ledcSetup(LED_CHANNEL, MOTOR_PWM_FREQ, 8);
  ledcAttachPin(LED_PIN, LED_CHANNEL);
}

void loop() {
  current_millis = millis();
  // Read battery voltage
  if (current_millis - last_voltage_read_millis > VOLTAGE_READ_INTERVAL) {
    voltage_control();  
    last_voltage_read_millis = current_millis;
  }

  led_control();

  
  // Start break and handshake procedure if ACK wasn't received within 80ms after the handshake
  if ((state == HANDSHAKE) && (!break_cond_ongoing) && (!break_high_ongoing) && (current_millis - previous_millis > HANDSHAKE_INTERVAL)) {
    digitalWrite(TX_PIN, LOW); //Begin 500ms UART break condition for EV3
    break_cond_millis = current_millis;
    break_cond_ongoing = true;
    handshake_finished = false;
  }
  
  // End break condition LOW, set pin to HIGH for 1ms
  if ((break_cond_ongoing) && (!break_high_ongoing) && (current_millis - break_cond_millis >= BREAK_COND_TIME)) {
    digitalWrite(TX_PIN, HIGH);
    current_millis = millis();
    break_high_millis = current_millis;
    break_cond_ongoing = false;
    break_high_ongoing = true;
  }

  // 1ms passed since TX HIGH, begin handshake
  if ((break_high_ongoing) && (!handshake_finished) && (current_millis - break_high_millis > 0)) {
    soft_serial.begin(DEFAULT_BAUD_RATE);
    Handshake(soft_serial);
    digitalWrite(TX_PIN, LOW);
    current_millis = millis();
    previous_millis = current_millis;
    break_high_ongoing = false;
    handshake_finished = true;
  }

  if (handshake_finished) {

    if(soft_serial.available()) {
        char received_char = soft_serial.read();

        switch(received_char) {
          //ACK received, begin regular communication
          case 0x04:
              current_millis = millis();
              if ((current_millis - previous_millis <= HANDSHAKE_INTERVAL)) {
                state = CONNECTED;
                // Change comm baud rate if specifying different than default comm speeed (comment the code if keeping default speed)
                soft_serial.begin(COMM_BAUD_RATE);
              }
              break;

          //NACK received, send information
          case 0x02: 
              //Send 1 byte + arbitrary byte for read compatibility
              soft_serial.write(0xC8);
              soft_serial.write(motor_pwms[pwm_send_index] + 16*pwm_send_index);
              soft_serial.write('\0');
              soft_serial.write(0xC8 ^ (motor_pwms[pwm_send_index] + 16*pwm_send_index) ^ '\0' ^ 0xFF);

              //Increment index for multiplexing
              pwm_send_index++;
              if (pwm_send_index == 4) {
                pwm_send_index = 0;
              }

              last_write_millis = current_millis;
              last_nack_millis = current_millis;
              break;

          //WRITE/Data/checksum message
          default: 
              // Ignore checksum byte
              if (checksum_expected) {
                checksum_expected = false;
              }

              // WRITE message
              else if ((bytes_to_read == 0) && (received_char >= 0x44) && (received_char <= 0x7C)) {
                received_char = received_char & EV3_WRITE_MASK; //AND mask to get length exponent
                received_char = received_char >> 3;
                bytes_to_read = pow(2, received_char); //Set incoming data length to 2^result
              }
              //Set Motor based on message byte, ignore if 0x11 (unknown) byte
              else if (bytes_to_read > 0) {
                  bytes_to_read--;
                  if (received_char != 0x11) {
                    setMotor(received_char);
                  }
                  // Prepare for checksum byte after parsing last payload byte
                  if (bytes_to_read == 0) {
                    checksum_expected = true;
                  }
              }
              break;
        }
    }

    //Write data independent of NACK message at set interval
    if ((current_millis - last_write_millis >= WRITE_INTERVAL) && (state == CONNECTED)) {
      // Uncomment if you want to send data independently in an interval of <1,100> ms
      // soft_serial.write(0xC8);
      // soft_serial.write(motor_pwms[pwm_send_index] + 16*pwm_send_index);
      // soft_serial.write('\0');
      // soft_serial.write(0xC8 ^ (motor_pwms[pwm_send_index] + 16*pwm_send_index) ^ '\0' ^ 0xFF);

      // //Increment index for multiplexing
      // pwm_send_index++;
      // if (pwm_send_index == 4) {
      //   pwm_send_index = 0;
      // }
      last_write_millis = current_millis;
    }

    //1000ms since last NACK --> sensor reset
    if ((current_millis - last_nack_millis >= NACK_TIMEOUT) && (state == CONNECTED)) {
      last_nack_millis = current_millis;
      state = HANDSHAKE;
    }

  }
}

//Parse read byte by the motor control protocol and set a motor accordingly
void setMotor(uint8_t val) {
    uint8_t motor_index = 0;
    bool motor_turn_on = false;
    bool polarity_forward = false;
    unsigned short int duty_cycle = 0;

    //Get bits of motor index (right shift to get bits 6 and 7 and return the value)
    motor_index = (val >> 6);

    //Get PWM duty cycle (combine with mask to get just the first 4 bits)
    duty_cycle = (val & DUTY_CYCLE_MASK);

    //Get ON/OFF state 
    if ((val & ON_OFF_MASK) != 0) {
      motor_turn_on = true;
    } 
    else {
      motor_turn_on = false;
    }
    //Get polarity
    if ((val & POLARITY_MASK) != 0) {
      polarity_forward = true;
    } 
    else {
      polarity_forward = false;
    }
    

    //Set specified motor to specified parameters if turned on, otherwise turn off
    if (motor_turn_on && duty_cycle != 0) {
        motors[motor_index].Set_Speed(duty_cycle);
        //Save motor PWM for data sendback
        motor_pwms[motor_index] = duty_cycle;
          if (polarity_forward) {
            motors[motor_index].Run(FORWARD);
          } else {
            motors[motor_index].Run(BACKWARD);
          }
    } 
    else {
        motors[motor_index].Run(RELEASE);
    }   
}

// Read battery voltage value and calculate average value
void voltage_control() {
  voltage_readout = readADC_Cal(analogRead(ADC_PIN));
  
  // Fill out the window at the beginning to avoid 0s skewing the average
  if (avg_index == 0) {
    for (uint8_t i = 0; i < AVG_WINDOW_SIZE; i++) {
      avg_window[i] = voltage_readout;
    }
  }


  //Calculate running average
  avg_window[avg_index] = voltage_readout;
  avg_index = (avg_index + 1) % AVG_WINDOW_SIZE;

  uint32_t sum = 0;
  for (uint8_t i = 0; i < AVG_WINDOW_SIZE; i++) {
    sum += avg_window[i];
  }
  uint32_t average = sum / AVG_WINDOW_SIZE;
  // Trigger shutdown procedure if battery voltage gets below threshold
  if (average <= 860 && state != LOW_BATTERY) { //860 --> 10.8V
    state = LOW_BATTERY;
    low_voltage_trigger_millis = millis();
  }

  // Check if 10 seconds have passed since low voltage trigger, enter deep sleep
  if (state == LOW_BATTERY) {
    current_millis = millis();
    if (current_millis - low_voltage_trigger_millis >= LOW_BATTERY_TIMEOUT) {
      esp_deep_sleep_start();
    }
  }
}

// Control GPIO LED
void led_control() {
  led_current_millis = millis();
  // Slow flashing
  if (state == HANDSHAKE) {
    // Switch duty cycle after timer reset
    if (led_current_millis - led_previous_millis > LED_INTERVAL) {
      if (led_duty_cycle == 0) {
        led_duty_cycle = 255;      
      }
      else {
        led_duty_cycle = 0;
      }
      ledcWrite(LED_CHANNEL, led_duty_cycle);
      led_previous_millis  = led_current_millis;
    }
  }
  // Low PWM LED on if connected to EV3
  else if (state == CONNECTED) {
    ledcWrite(LED_CHANNEL, LED_DUTY_CYCLE_LOW);
  }
  // Fast flashing if battery is low
  else if (state == LOW_BATTERY) {
    // Switch out duty cycle after timer reset
    if (led_current_millis - led_previous_millis > LED_INTERVAL/5) {
        if (led_duty_cycle == 0) {
          led_duty_cycle = 255;      
        }
        else {
          led_duty_cycle = 0;
        }
        ledcWrite(LED_CHANNEL, led_duty_cycle);
      led_previous_millis = led_current_millis;
    }
  }
}


//Calibrate ADC output
uint32_t readADC_Cal(int ADC_Raw)
{
  esp_adc_cal_characteristics_t adc_chars;
  esp_adc_cal_characterize(ADC_UNIT_1, ADC_ATTEN_DB_11, ADC_WIDTH_BIT_12, 1100, &adc_chars);
  return(esp_adc_cal_raw_to_voltage(ADC_Raw, &adc_chars));
}

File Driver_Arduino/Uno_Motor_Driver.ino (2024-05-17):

#include <Wire.h>
#include <AFMotor.h>
#define SLAVE_ADDRESS 0x12


//Set up all four motors
    AF_DCMotor motor1(1);
    AF_DCMotor motor2(2);
    AF_DCMotor motor3(3);
    AF_DCMotor motor4(4);
//Array of motors (easier motor setting by just setting the motor at a parsed index)
AF_DCMotor motors[4] = {motor1, motor2, motor3, motor4};

//Mask for motor on/off bit (bit 5)
uint8_t on_off_mask = 0x20;
//Mask for motor polarity bit (bit 4)
uint8_t polarity_mask = 0x10;
//Mask for motor duty cycle (bits 0-3)
uint8_t duty_cycle_mask = 0x0F;

uint8_t val, flag=0;

void setup()
{
  //Listen to I2C communication on the defined slave device address
  Wire.begin(SLAVE_ADDRESS);
  Wire.onReceive(receiveData);
}

void loop()
{
  if(flag==1)
   {
    setMotor(val);
    flag=0;
   }
}

void receiveData(int byteCount)
{
  //Incoming message byte
  while(Wire.available()>0)
  {
    val = Wire.read();
    flag=1;
  }
}

//Parse read byte by the motor control protocol and set a motor accordingly
void setMotor(unsigned short int val) {
    unsigned short int motor_index = 0;
    bool motor_turn_on = false;
    bool polarity_forward = false;
    unsigned short int duty_cycle = 0;
    //Get bits of motor index (right shift to get bits 6 and 7 and return the value)
    motor_index = (val >> 6);
    //Get ON/OFF state 
    if ((val & on_off_mask) != 0) {
      motor_turn_on = true;
    } else {
      motor_turn_on = false;
    }
    //Get polarity
    if ((val & polarity_mask) != 0) {
      polarity_forward = true;
    } else {
      polarity_forward = false;
    }

    //Get PWM duty cycle (combine with mask to get just the first 4 bits)
    duty_cycle = (val & duty_cycle_mask);

    //Set specified motor to specified parameters if turned on, otherwise turn off
    if (motor_turn_on && duty_cycle != 0) {
        motors[motor_index].setSpeed((duty_cycle*255)/15);
          if (polarity_forward) {
            motors[motor_index].run(FORWARD);
          } else {
            motors[motor_index].run(BACKWARD);
          }
    } else {
        motors[motor_index].run(RELEASE);
    }   
}

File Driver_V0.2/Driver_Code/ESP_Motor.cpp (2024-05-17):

/*
* File:   ESP32_Motor.cpp
*
* Desc:   Classes, methods and functions to initialize and control
*         Power Function motor via *ledc* functions, based on the Adafruit
*         Motor Shield library (https://www.arduino.cc/reference/en/libraries/adafruit-motor-shield-library/)
*
* Author: Daniel Blaško
*/


#if (ARDUINO >= 100)
  #include "Arduino.h"
#endif
#include "ESP_Motor.h"

uint8_t motor1_pwm, motor2_pwm, motor3_pwm, motor4_pwm;

// Initialize motors, set up PWM channels for both motor pins
inline void Init_PWM1() {
    motor1_pwm = 0;
    ledcSetup(PWM_CHANNEL_1A, MOTOR_PWM_FREQ, PWM_RESOLUTION);
    ledcSetup(PWM_CHANNEL_1B, MOTOR_PWM_FREQ, PWM_RESOLUTION);
  
    ledcAttachPin(MOTOR_1A, PWM_CHANNEL_1A);
    ledcAttachPin(MOTOR_1B, PWM_CHANNEL_1B);
}

inline void Init_PWM2() {
    motor2_pwm = 0;
    ledcSetup(PWM_CHANNEL_2A, MOTOR_PWM_FREQ, PWM_RESOLUTION);
    ledcSetup(PWM_CHANNEL_2B, MOTOR_PWM_FREQ, PWM_RESOLUTION);
  
    ledcAttachPin(MOTOR_2A, PWM_CHANNEL_2A);
    ledcAttachPin(MOTOR_2B, PWM_CHANNEL_2B);
}

inline void Init_PWM3() {
    motor3_pwm = 0;
    ledcSetup(PWM_CHANNEL_3A, MOTOR_PWM_FREQ, PWM_RESOLUTION);
    ledcSetup(PWM_CHANNEL_3B, MOTOR_PWM_FREQ, PWM_RESOLUTION);
  
    ledcAttachPin(MOTOR_3A, PWM_CHANNEL_3A);
    ledcAttachPin(MOTOR_3B, PWM_CHANNEL_3B);
}

inline void Init_PWM4() {
    motor4_pwm = 0;
    ledcSetup(PWM_CHANNEL_4A, MOTOR_PWM_FREQ, PWM_RESOLUTION);
    ledcSetup(PWM_CHANNEL_4B, MOTOR_PWM_FREQ, PWM_RESOLUTION);
  
    ledcAttachPin(MOTOR_4A, PWM_CHANNEL_4A);
    ledcAttachPin(MOTOR_4B, PWM_CHANNEL_4B);
}

// Motor class constructor
Motor::Motor(uint8_t num) {
  motor_num = num;

  switch (num) {
  case 1:
    Init_PWM1();
    break;
  case 2:
    Init_PWM2();
    break;
  case 3:
    Init_PWM3();
    break;
  case 4:
    Init_PWM4();
    break;
  }
}

// Generate PWM signals to run motors
void Motor::Run(uint8_t cmd) {
  uint8_t a, b;
  switch (motor_num) {
  case 1:
    a = PWM_CHANNEL_1A; 
    b = PWM_CHANNEL_1B; 
    pwm = motor1_pwm;
    break;

  case 2:
    a = PWM_CHANNEL_2A; 
    b = PWM_CHANNEL_2B; 
    pwm = motor2_pwm;
    break;

  case 3:
    a = PWM_CHANNEL_3A; 
    b = PWM_CHANNEL_3B; 
    pwm = motor3_pwm;
    break;

  case 4:
    a = PWM_CHANNEL_4A; 
    b = PWM_CHANNEL_4B; 
    pwm = motor4_pwm;
    break;

  default:
    return;
  }
  
  switch (cmd) {
  case FORWARD:
    ledcWrite(a, pwm);
    ledcWrite(b, 0);
    break;
  case BACKWARD:
    ledcWrite(a, 0);
    ledcWrite(b, pwm);
    break;
  case RELEASE:
    ledcWrite(a, 0);
    ledcWrite(b, 0);
    break;
  }
}

// Set duty cycle for motor PWM signals
void Motor::Set_Speed(uint8_t speed) {
  switch (motor_num) {
  case 1:
    motor1_pwm = speed;
    break;
  case 2:
    motor2_pwm = speed;
    break;
  case 3:
    motor3_pwm = speed;
    break;
  case 4:
    motor4_pwm = speed;
    break;
  }
}

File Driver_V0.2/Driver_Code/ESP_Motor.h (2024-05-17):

/*
* File:   ESP32_Motor.h
*
* Desc:   Header file for the ESP32_Motor.cpp file
*
* Author: Daniel Blaško
*/

#ifndef _ESP_Motor_h_
#define _ESP_Motor_h_

// Motor GPIO pins
#define MOTOR_1A 33
#define MOTOR_1B 32
#define MOTOR_2A 26
#define MOTOR_2B 25
#define MOTOR_3A 12
#define MOTOR_3B 27
#define MOTOR_4A 16
#define MOTOR_4B 4

// PWM channels for motor control
#define PWM_CHANNEL_1A 1
#define PWM_CHANNEL_1B 2
#define PWM_CHANNEL_2A 3
#define PWM_CHANNEL_2B 4
#define PWM_CHANNEL_3A 5
#define PWM_CHANNEL_3B 6
#define PWM_CHANNEL_4A 7
#define PWM_CHANNEL_4B 8
#define LED_CHANNEL 9

// PWM attribute values
#define MOTOR_PWM_FREQ 1200
#define PWM_RESOLUTION 4

// Motor run modes
#define FORWARD 1
#define BACKWARD 2
#define RELEASE 3

class Motor
{
 public:
  Motor(uint8_t motor_num);
  void Run(uint8_t);
  void Set_Speed(uint8_t);

 private:
  uint8_t motor_num, pwm;
};

#endif
